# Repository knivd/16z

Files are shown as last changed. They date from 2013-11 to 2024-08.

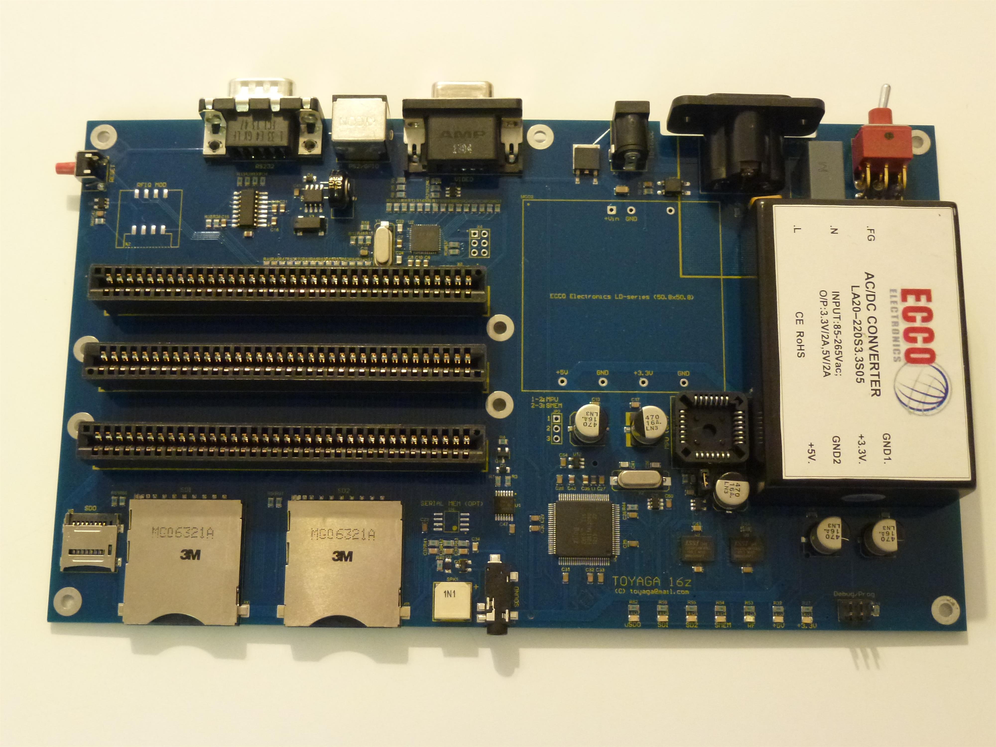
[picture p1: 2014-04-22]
graphics/P1010165.JPG

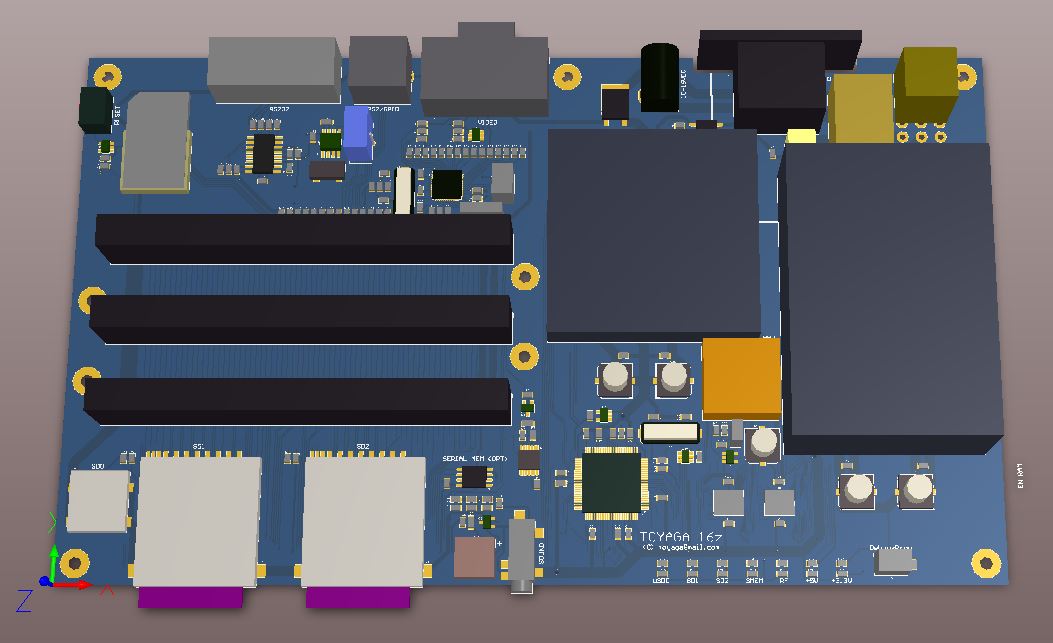
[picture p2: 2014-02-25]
graphics/3D.JPG

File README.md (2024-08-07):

16z
===

The 'Contemporary Retro' Computer

'640K ought to be enough for anyone...'

Although it is now known that Bill Gates never actually said this, whoever did was probably not far from the truth. How the resources in a system are used by the software is what really matters. Of course, this assumes a system is properly designed to utilise well-written software.

Personal computing has come a long way, but that doesn't mean the path was always ideal. There are still numerous real-life applications where an old DOS-based (or similar) machine works just as well, if not better, than the latest multicore, gigahertz beast running the most recent colourful software disaster. Along the way, computers have somehow lost their direction, and users have lost their enthusiasm and inspiration.

This project is about a computer built in the spirit of the old ways, taking inspiration from where things went wrong and attempting to rectify it by creating a retro-style computer with modern 21st-century components. Large memory and maximum speed are not the aims, nor are great graphics or the ability to run any 'nix OS. Instead, the focus is on being 'cute' (as much as you can apply that to a board), inspiring, open, and allowing the easy creation of user-designed add-on boards in any hobby lab.

Zilog's Z16F is a true gem among today's processors, dominated by Intel, ARM, and MIPS. Although it operates at a frequency considered very low by modern standards, it is amazing due to its very clean and well-thought-out internal architecture. It is also one of the very few Von-Neumann architecture CISC processors available on the market now, making it highly suitable for early introduction into microprocessor systems design and programming. Its parameters and structure revive that long-forgotten urge to create—a processor in the real style of the 'golden age' of personal computing.

The ultimate aim: to be simple and accessible to literally everyone and to demonstrate that a good, usable computer does not need 'giga'-parameters. It is all a matter of properly written software.

Possible applications: accounting, early programming education, data terminals, retro-style gaming, hobby design, and programming.

And most importantly, to bring some entertainment while working on it...

Check out the project's Wiki pages for more detailed information.

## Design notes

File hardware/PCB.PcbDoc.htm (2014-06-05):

Reporting Options

# File in Previous Format

Date | : | 5/06/2014
Time | : | 10:54:14 AM
Filename | : | D:\Work\16z\hardware\PCB.PcbDoc

Version | Warning
Release 14 | CAUTION - The Differential Pairs Routing rule added support for control of the width. Be aware that Width rules pertaining to differential pairs need to be manually moved to the Differential Pairs Routing rule.

This file was generated by an earlier version of the software

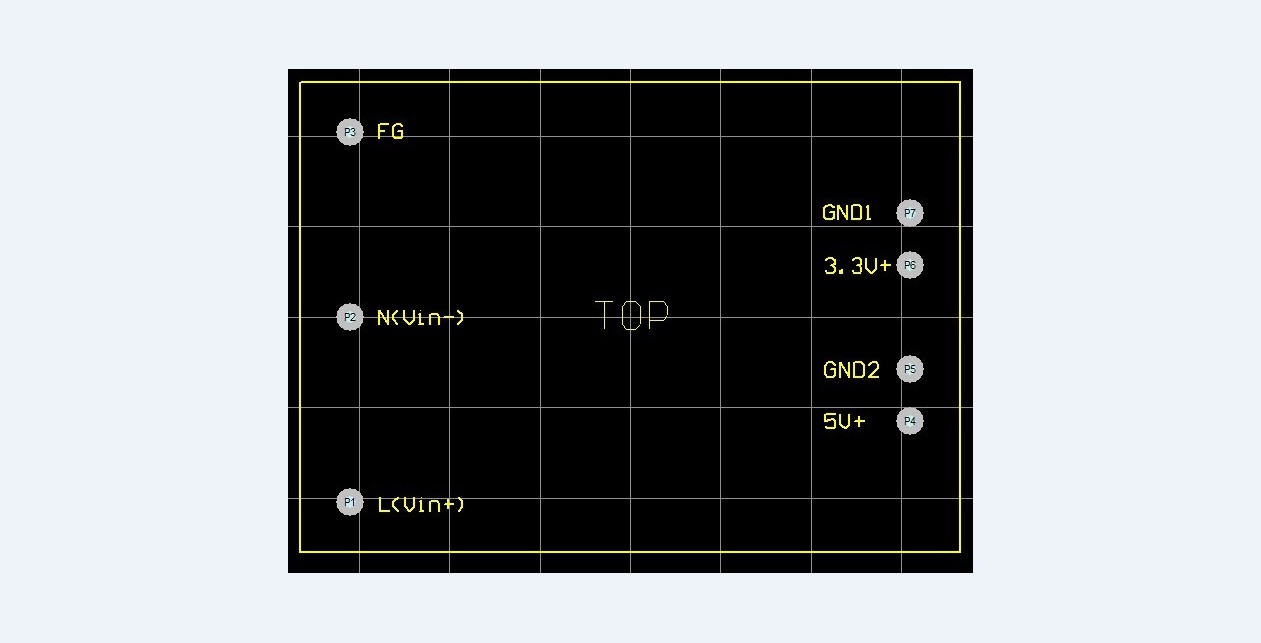
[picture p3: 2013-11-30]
docs/LA20-220S3.3S05.jpg

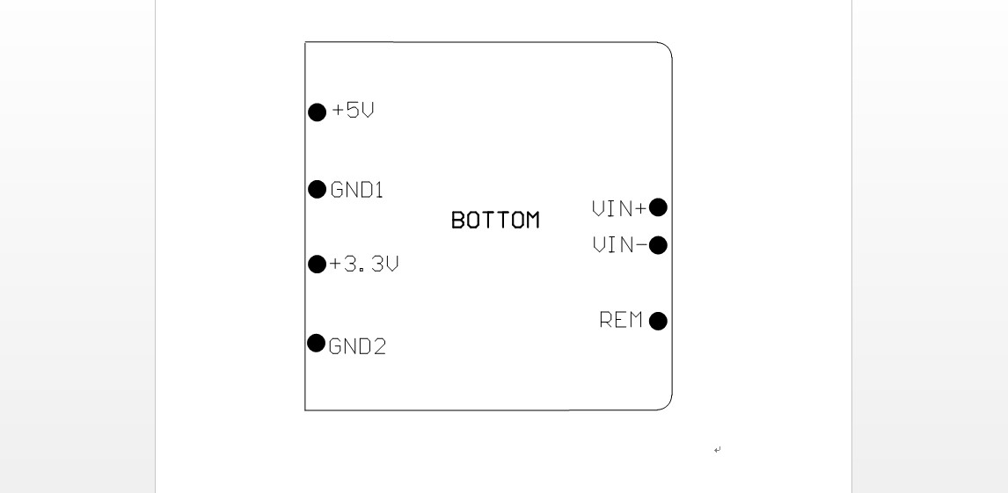
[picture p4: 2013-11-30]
docs/LD20-12S05S3.3.jpg

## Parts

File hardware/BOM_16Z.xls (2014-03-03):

Comment | Pattern | Quantity | Vendor 1 | Order Code 1 | Vendor 2 | Order Code 2 | Components | Description
LA25-220S3.3S05 | ECCO AC-DC (70x48) | 1 | ECCO | LA25-220S3.3S05 | ECCO | LA25-220S3.3S05 | MOD1 | Miniature AC/DC module
LD25-12S05S3.3 | ECCO DC-DC (50.8x50.8) | 1 | ECCO | LD25-12S05S3.3 | ECCO | LD25-12S05S3.3 | MOD2 | Miniature DC/DC module
KON-SIM-01 | KON-SIM-01 | 1 | IQRF | KON-SIM-01 | IQRF | KON-SIM-01 | X2 | SIM/microSIM 6-pin connector
470u/16V | 8.5 x 8.5 | 5 | Mouser | 661-EMZJ160A471MHA0G | Digikey | PCE3892CT-ND | C1, C9, C12, C18, C51 | Polar capacitor
1u/50V | _1206 | 1 | Mouser | 77-VJ1206V105MXATBC | Digikey | 1276-1068-1-ND | C14 | Capacitor
R46KI3330 | X2_15MM | 1 | Mouser | 80-R46KI333050N1M | Digikey | 399-6809-ND | C2 | Capacitor
27p | _0805 | 2 | Mouser | 77-VJ0805A270GXXPBC | Digikey | 1276-1285-1-ND | C22, C24 | Capacitor
100n | _0805 | 26 | Mouser | 77-VJ0805Y104MXXAC | Digikey | 1276-1003-1-ND | C3, C8, C11, C13, C17, C23, C25, C26, C27, C28, C29, C30, C31, C32, C33, C42, C43, C44, C45, C46, C47, C49, C50, C52, C53, C54 | Capacitor
470n | _0805 | 1 | Mouser | 77-VJ0805Y474JXJTBC | Digikey | 1276-1039-1-ND | C34 | Capacitor
18p | _0805 | 2 | Mouser | 77-VJ0805A180GXACBC | Digikey | 1276-1107-1-ND | C36, C41 | Capacitor
4n7 | _0805 | 4 | Mouser | 77-VJ0805Y472KXAMC | Digikey | 1276-1155-1-ND | C4, C37, C38, C39 | Capacitor
10u | _0805 | 1 | Mouser | 810-C2012X5R1A106K-3 | Digikey | 1276-1096-1-ND | C40 | Capacitor
EECS0HD334V | D10.5 x L5.5 | 1 | Mouser | 667-EEC-S0HD334V | Digikey | P11065-ND | C48 | Polar capacitor
4u7 | _0805 | 3 | Mouser | 77-VJ0805V475ZXQTBC | Digikey | 1276-1065-1-ND | C5, C6, C10 | Capacitor
1u | _0805 | 7 | Mouser | 77-VJ0805V105ZXJCBC | Digikey | 1276-1029-1-ND | C7, C15, C16, C19, C20, C21, C35 | Capacitor
BAT54WS | SOD-323 (MicroMELF) | 2 | Mouser | 78-BAT54WS-E3-08 | Digikey | BAT54WS-TPCT-ND | D1, D3 | Schottky diode
BAS21VD | SOT23-6 | 1 | Mouser | 771-BAS21VD135 | Digikey | 568-5819-1-ND | D2 | Diode (triple)
RB751V40T1G | SOD-323 (MicroMELF) | 1 | Mouser | 863-RB751V40T1G | Digikey | 568-8119-1-ND | D4 | Schottky diode
TRF600-150-2 | Fuse 5.1mm pitch | 1 | Mouser | 650-TRF600-150-2 | Digikey | TRF600-150-ND | F1 | Resettable fuse
MD-60SM | MD-60SM | 1 | Mouser | 806-KMDLX-6S-AS | Digikey | P-2260-ND | J1 | 6-pin mini-DIN connector (female) PS/2
TE1734530 | DB15F R/A VGA | 1 | Mouser | 571-1-1734530-1 | Digikey | A35116-ND | J2 | DB15 (3 rows) connector R/A
DB9-M | DB9M R/A | 1 | Mouser | 649-ID09P33E4GX00LF | Digikey | S9575-ND | J3 | DB9 connector
STX-3500-5N | STX-3500 | 1 | Mouser | 806-STX-3500-5NTR | Digikey | SC1489-1-ND | J4 | Phono Jack (stereo)
SIL2-M | 2011-2X02S | 1 | Mouser | 649-68000-202HLF | Digikey | 952-1770-ND | JP1 | Single row, 2-way connector/jumper
SIL3-M | 2011-2X03S | 1 | Mouser | 649-68000-203HLF | Digikey | 952-1777-ND | JP2 | Single row, 3-way connector/jumper
FR120R | _0805 | 1 | Mouser | 623-2508056007Z0 | Digikey | MH2029-600YCT-ND | L1 | Inductor
0805GRN | _0805+ | 2 | Mouser | 720-LGR971-KN-1 | Digikey | 475-1410-1-ND | LED1, LED2 | Light Emitting Diode
0805BLU | _0805+ | 1 | Mouser | 859-LTST-C171TBKT | Digikey | 732-4982-1-ND | LED3 | Light Emitting Diode
0805YLW | _0805+ | 3 | Mouser | 720-LYR976-PS-36 | Digikey | 475-2560-1-ND | LED4, LED5, LED6 | Light Emitting Diode
0805RED | _0805+ | 1 | Mouser | 720-LSR976-NR-1 | Digikey | 475-1278-1-ND | LED7 | Light Emitting Diode
MMUN2233 | SOT23-3 | 2 | Mouser | 863-MMUN2233LT1G | Digikey | MMUN2233LT1GOSCT-ND | Q1, Q3 | NPN biased bipolar transistor
DMP4015SK3 | TO252-3N | 1 | Mouser | 621-DMP4015SK3-13 | Digikey | DMP4015SK3-13DICT-ND | Q2 | P-channel FET transistor
470k | _0805 | 2 | Mouser | 660-RK73H2ATTD4703F | Digikey | P470KCCT-ND | R1 | Resistor
470R | _0805 | 3 | Mouser | 660-RK73H2ATTD4700F | Digikey | P470CCT-ND | R11, R19, R31 | Resistor
100k | _0805 | 10 | Mouser | 660-RK73H2ATTD1003F | Digikey | P100KCCT-ND | R2, R4, R35, R36, R49, R56, R57, R60, R61, R71 | Resistor
75R | _0805 | 3 | Mouser | 660-RK73H2ATTD75R0F | Digikey | P75.0CCT-ND | R21, R22, R23 | Resistor
510R | _0805 | 6 | Mouser | 660-RK73H2ATTD5100F | Digikey | P510CCT-ND | R27, R53, R54, R55, R59, R62 | Resistor
330R | _0805 | 4 | Mouser | 660-RK73H2ATTDD3300F | Digikey | P330CCT-ND | R28, R30, R33, R34 | Resistor
10k | _0805 | 20 | Mouser | 660-RK73H2ATTD1002F | Digikey | P10.0KCCT-ND | R3, R12, R15, R39, R45, R46, R47, R48, R50, R51, R52, R58, R63, R64, R65, R66, R67, R68, R69, R70 | Resistor
820R | _0805 | 1 | Mouser | 660-RK73H2ATTDD8200F | Digikey | P820CCT-ND | R32 | Resistor
33R | _0805 | 1 | Mouser | 660-RK73H2ATTD33R0F | Digikey | P33.0CCT-ND | R40 | Resistor
20R | _0805 | 1 | Mouser | 660-RK73H2ATTD20R0F | Digikey | P20.0CCT-ND | R44 | Resistor
15k | _0805 | 3 | Mouser | 660-RK73H2ATTD1502F | Digikey | P15.0KCCT-ND | R5, R13, R20 | Resistor
8k2 | _0805 | 3 | Mouser | 660-RK73H2ATTD8201F | Digikey | P8.20KCCT-ND | R6, R14, R24 | Resistor
1k | _0805 | 9 | Mouser | 660-RK73H2ATTD1001F | Digikey | P1.00KCCT-ND | R7, R10, R18, R29, R37, R38, R41, R42, R43 | Resistor
3k9 | _0805 | 3 | Mouser | 660-RK73H2ATTD3901F | Digikey | P3.90KCCT-ND | R8, R16, R25 | Resistor
2k | _0805 | 3 | Mouser | 660-RK73H2ATTD2001F | Digikey | P2.00KCCT-ND | R9, R17, R26 | Resistor
SDR08540M3 | SDR08540M3-01 | 1 | Mouser | 810-SDR08540M3-01 | Digikey | 445-4832-1-ND | SPK1 | Speaker/Buzzer
E201MD1ABE | E201MD1ABE | 1 | Mouser | 611-E201-001 | Digikey | CKN1521-ND | SW1 | Switch
SKHHLSA010 | SKHH-HORIZONTAL | 1 | Mouser | 688-SKHHLS | Digikey | EG1840-ND | SW2 | Switch, Momentary, Normal Open
SN74LVC00APW | TSOP65P640-14N | 1 | Mouser | 595-SN74LVC00APWR | Digikey | 296-1216-1-ND | U1 | Quad NAND
SN74AUP1G57DBV | SOT23-6 | 1 | Mouser | 595-SN74AUP1G57DBVR | Digikey | 296-19082-1-ND | U10 | Programmable logic element
SN74LVC1G126DBV | SOT23-5 | 1 | Mouser | 595-74LVC1G126DBVRG4 | Digikey | 296-11605-1-ND | U11 | Buffer gate with non-invertinng Enable input
SN74AHC1G08DBV | SOT23-5 | 1 | Mouser | 595-SN74AHC1G08DBVR | Digikey | 296-1091-1-ND | U12 | 2-INPUT AND GATE
FT800Q | QFN50P700X700-48W2N | 1 | Mouser | 895-FT800Q-R | Digikey | 768-1185-1-ND | U2 | Embedded Video Engine
MAX3232D | SOIC16 | 1 | Mouser | 595-MAX3232ECDR | Digikey | 296-13094-1-ND | U3 | Dual EIA-232 drivers
Z16F2811AL20EG | LQFP100 | 1 | Mouser | 692-Z16F2811AL20SG | Digikey | 269-4533-ND | U5 | 16-bit microcontroller/microprocessor
MCP1319MT-29LE/OT | SOT23-5 | 1 | Mouser | 579-MCP1319MT29LE/OT | Digikey | MCP1319MT-29LE/OTCT-ND | U6 | Voltage Supervisor
IS66WVE4M16BLL | BGA75P6X8-48 | 2 | Mouser | 870-66WVE4M16BLL70BL | Digikey | Not available | U7, U8 | 4M x 16 high speed asynchronous pseudostatic RAM
ISL12024IBZ | SOIC8 | 1 | Mouser | 968-ISL12024IBZ-T | Digikey | ISL12024IBZ-TCT-ND | U9 | Real-Time Clock/Calendar with Embedded Unique ID
LTV354T | SO4 | 1 | Mouser | 859-LTV-354T | Digikey | 160-1333-1-ND | UC1 | Optocoupler AC
771W-AX2/01 | 771W-AX2/01 | 1 | Mouser | 562-771W-AX2/01 | Digikey | Q310-ND | X1 | Single row, 3-way connector
SD-RSMT | SD-RSMT | 2 | Mouser | 517-SD-RSMT-2-MQ | Digikey | 3M5646CT-ND | X10, X11 | SD card connector
47219-2001 | MOLEX_47219-2001 | 1 | Mouser | 538-47219-2001 | Digikey | WM6698CT-ND | X12 | microSD card connector
8428-11B1-RK-TP | PLCC28-T/H socket | 1 | Mouser | 517-8428-11B1-RK-TP | Digikey | 3M2811B1-ND | X13 | PLCC28 T/H socket
PJ-002A | KLD-0202 | 1 | Mouser | 163-7620E-E | Digikey | CP-002A-ND | X3 | Power Jack 2.1mm or 2.5mm
745-072-520-206 | 745-072-520-206 | 3 | Mouser | 587-745-072-520-206 | Digikey | A31721-ND | X5, X6, X7 | Dual row, 72-way connector
DIL6-M | 2011-2X03S | 1 | Mouser | 649-68602-406HLF | Digikey | 952-1779-ND | X9 | Dual row, 6-way connector
ABLS-12.000MHZ | HC49/SMT | 1 | Mouser | 815-ABLS-12-B2 | Digikey | 535-9067-1-ND | Y1 | Crystal Resonator
ABLS-18.432MHZ-B2-T | HC49/SMT | 1 | Mouser | 815-ABLS-18.432-B2 | Digikey | 535-9072-1-ND | Y2 | Crystal Resonator
CM200C-32.768KDZF-UT | Crystal 79X37 (4) | 1 | Mouser | 695-CM200C-327KF-U | Digikey | 300-8740-1-ND | Y3 | Crystal Resonator
DNF | SOIC127P760-8N | 1 |  |  |  |  | U4 | Standard 8-pin SPI memory
DNF | 2011-2X03S | 1 |  |  |  |  | X4 | Dual row, 6-way connector
DNF | 2011-1X04S | 1 |  |  |  |  | X8 | Single row, 4-way connector

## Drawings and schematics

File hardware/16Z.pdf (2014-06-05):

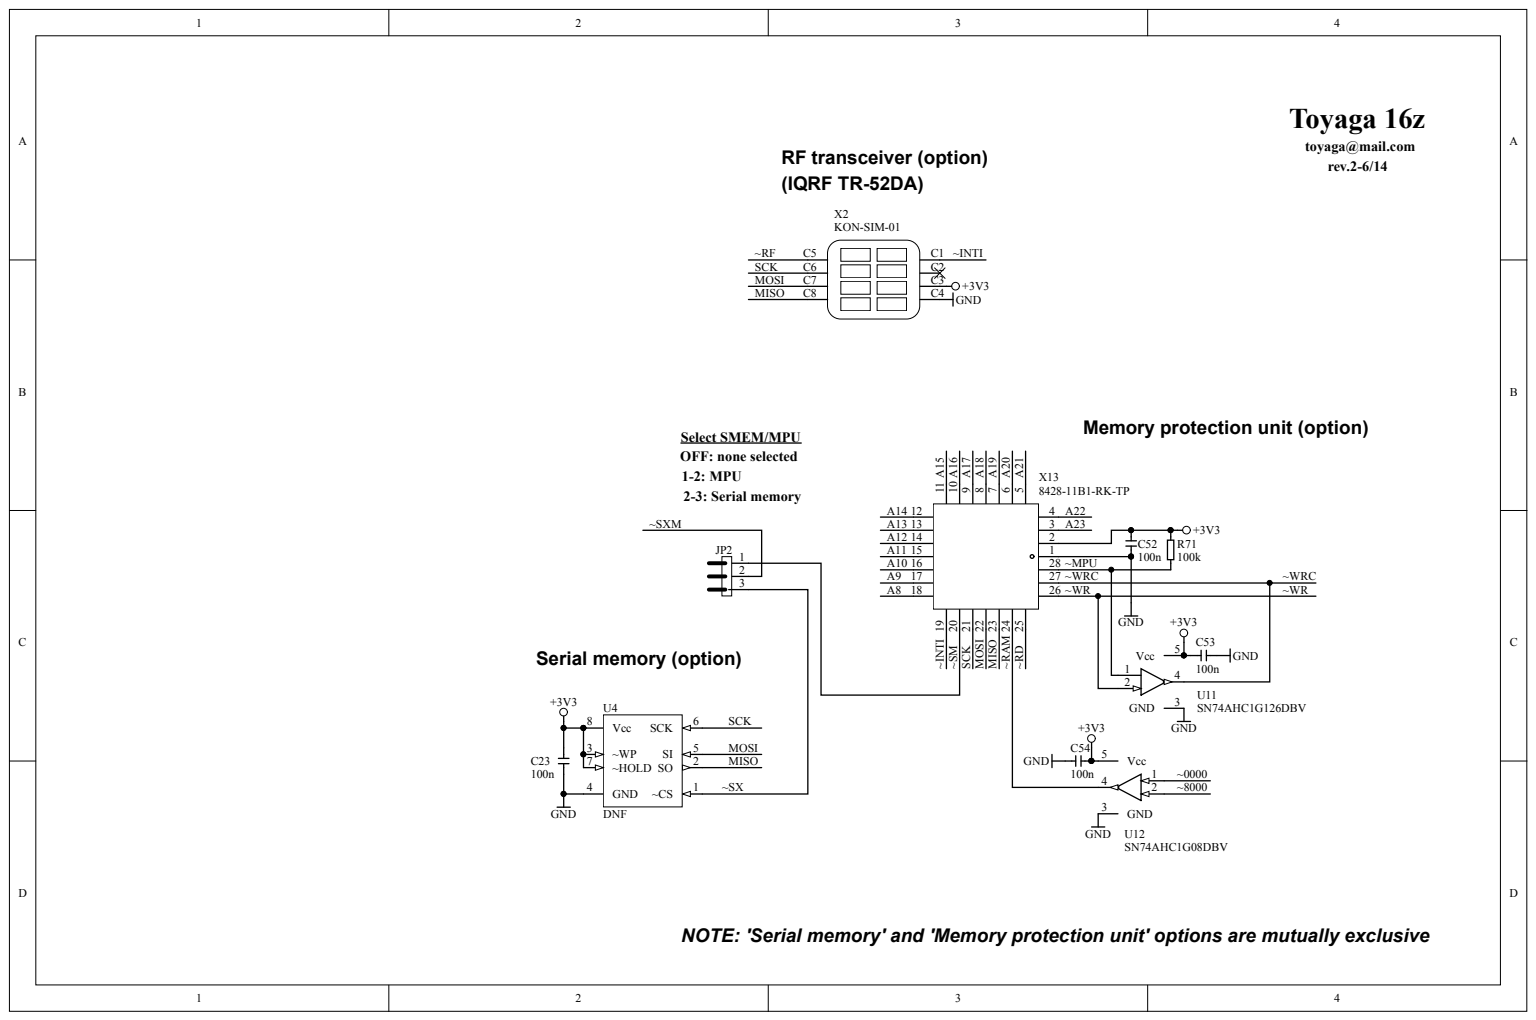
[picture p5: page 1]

Memory protection unit (option)

SCK

~HOLD 7 | | MISO

GND 4 | | ~SX

NOTE: 'Serial memory' and 'Memory protection unit' options are mutually exclusive

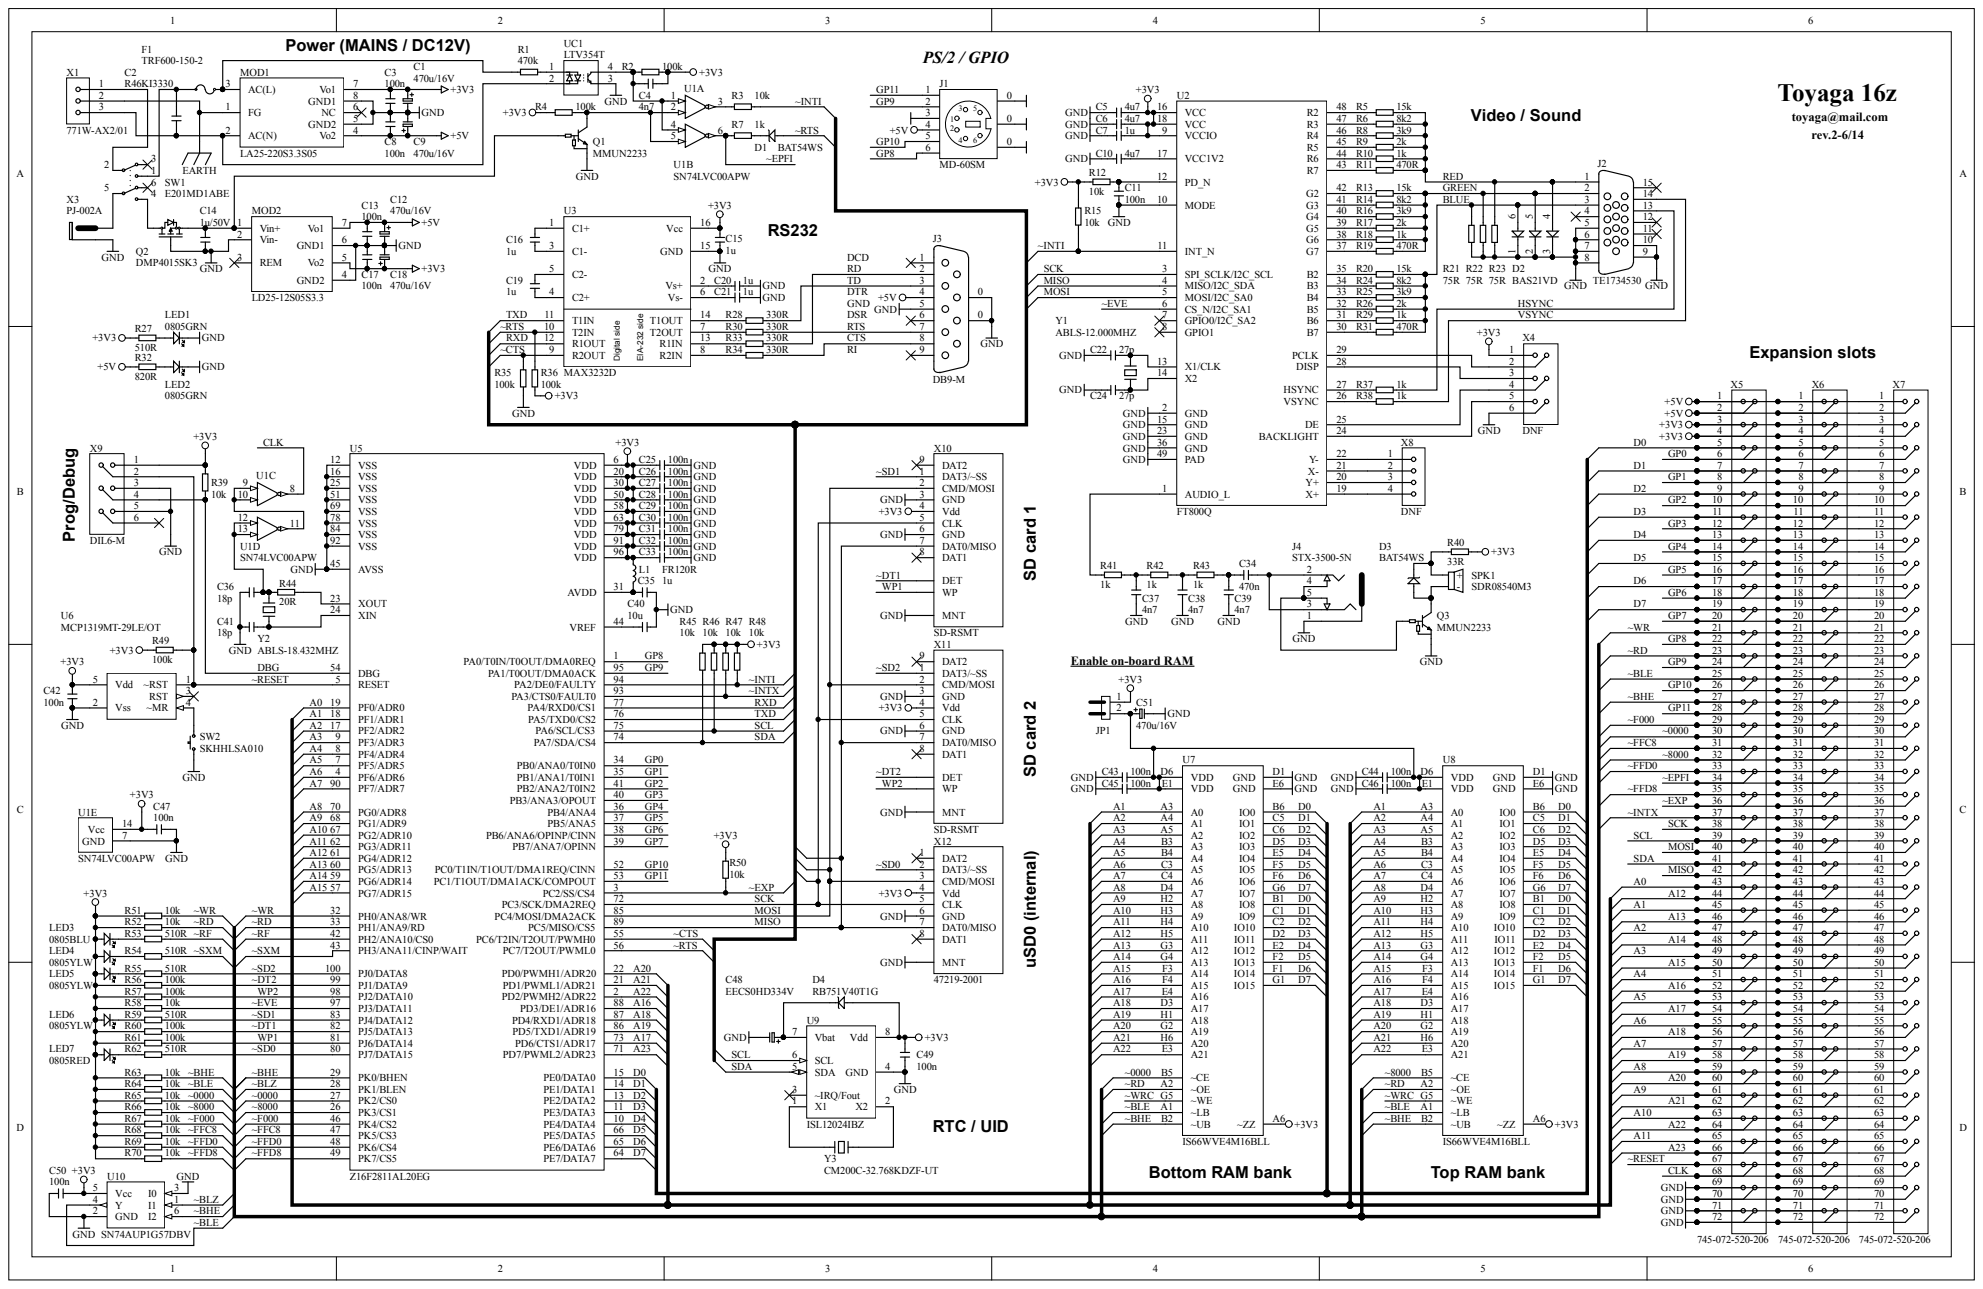
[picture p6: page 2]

6 R4 7 R4 8 k 1 0 k 1 0 k +3V3 | X1 0 | 2 3 | 2 | GND

uSD0 (internal) SD card 1 SD card 2

SDA SCL RXD TXD

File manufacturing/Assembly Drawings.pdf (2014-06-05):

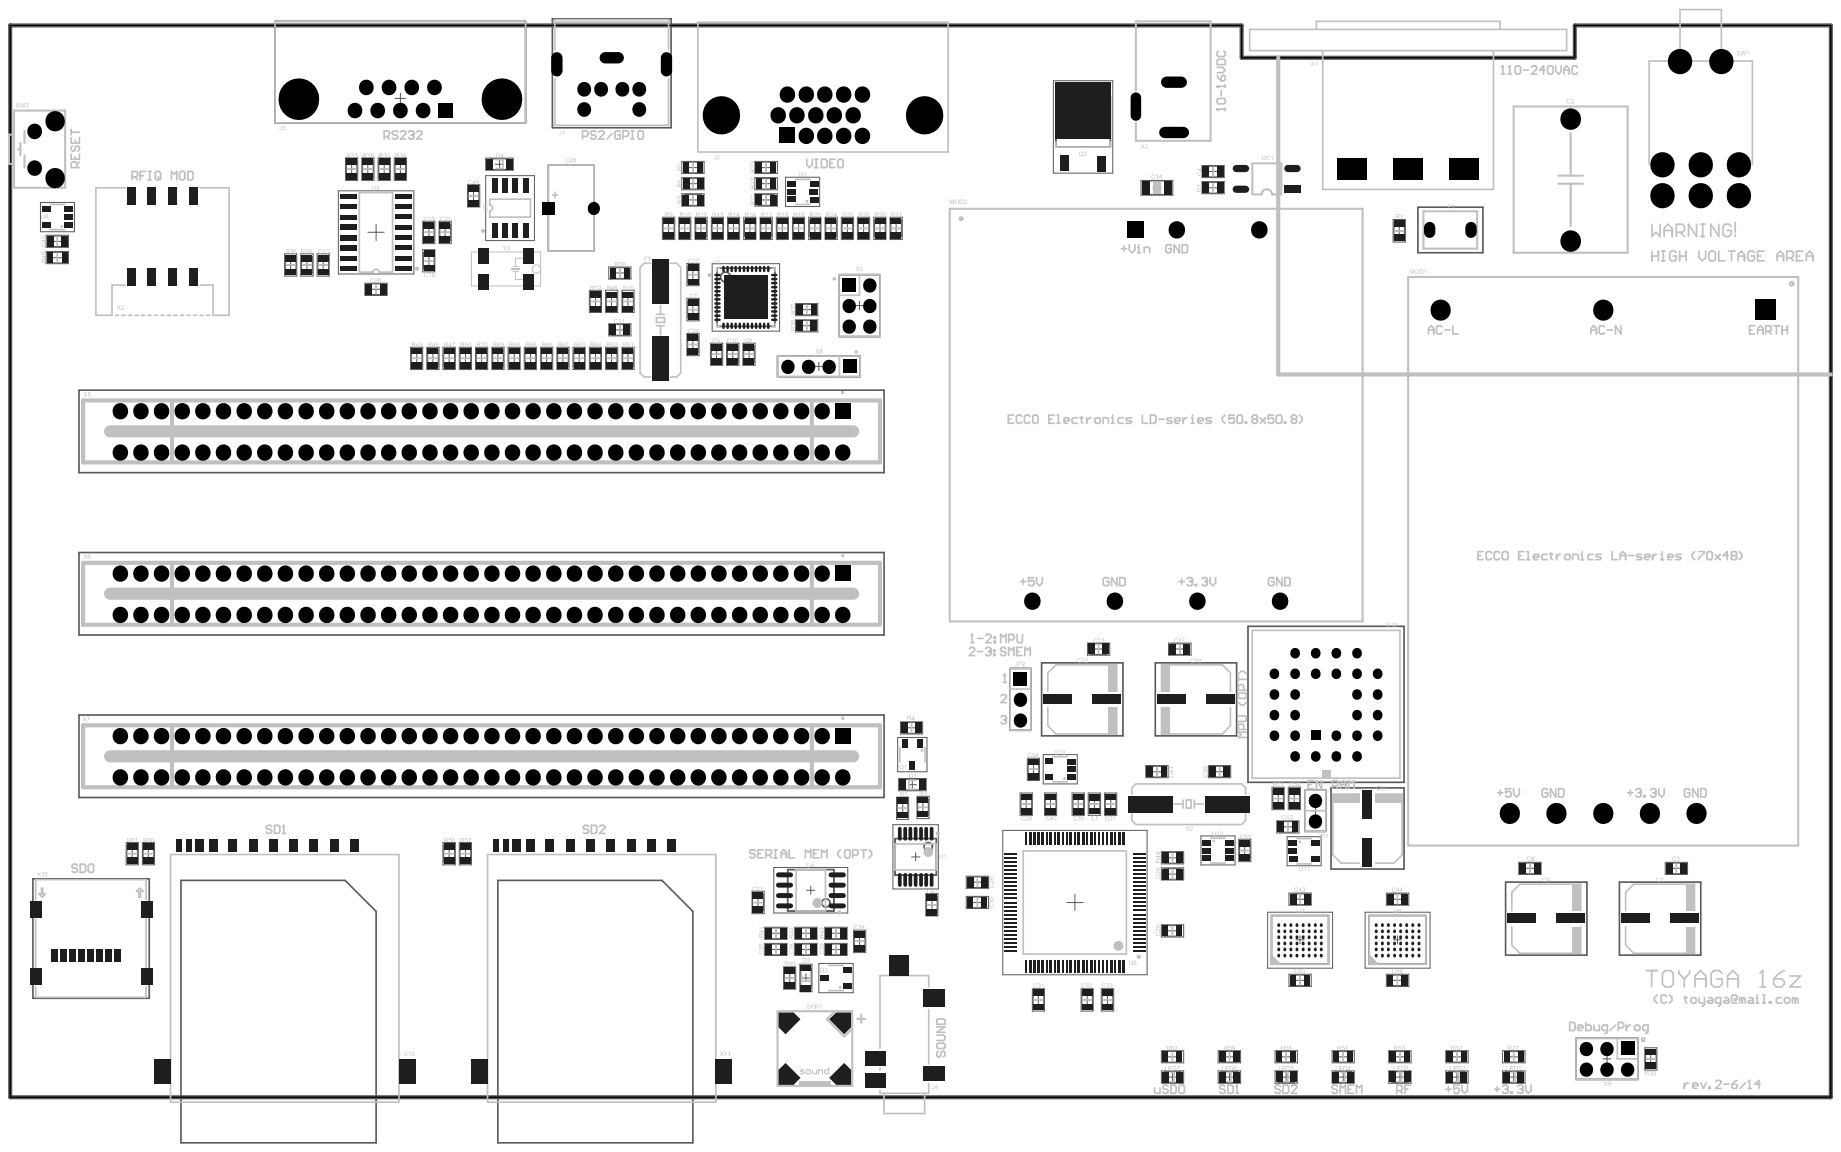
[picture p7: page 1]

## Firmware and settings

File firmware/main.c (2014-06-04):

#include <zneo.h>
#include <stdio.h>
#include "main.h"
#include "uart0.h"
#include "memory.h"
#include "spi.h"

FLASH_OPTION3=0x7f;

unsigned char sys_flags=0;	// system flags (see SYS_FLG_xxx constants)


void main(void) {

	WDTH=0x55; WDTH=0xaa; WDTHL=10000;	// initialise the watchdog reload register for 1s interval

	OSCDIV=0x00;	// no divider for the oscillator
    OSCCTL=0xe7; OSCCTL=0x18;	// unlock the oscillator control
    OSCCTL=0xf8;	// enable the external crystal oscillator and prepare the watchdog for later use
    asm("LD R0,#500000");   // a small delay for crystal oscillator stabilisation
    asm("label1: NOP");
    asm("DJNZ R0,label1");
	OSCCTL=0xe7; OSCCTL=0x18;	// unlock the oscillator control
    OSCCTL|=0x01;	// select the external crystal oscillator

	PADD=0xff; PBDD=0xff; PCDD=0x7b; PDDD=0xff; PEDD=0xff; PFDD=0xff; PGDD=0xff; PHDD=0xf3; PJDD=0x66; PKDD=0xff;	// set port directions
	PAHDE=0xff; PBHDE=0xff; PCHDE=0xff; PDHDE=0xff; PEHDE=0xff; PFHDE=0xff; PGHDE=0xff; PHHDE=0xff; PJHDE=0xff; PKHDE=0xff; // enable high current drive for all ports
	PAAFL=0xf0; PCAFL=0x38; PDAFH=0xff; PFAFL=0xff; PGAFL=0xff; PHAFH=0x03; PKAFL=0xfd;	// set port functions
	PCOUT=0xff; PHOUT=0xff; PJOUT=0xff;	// default high state for some ports
	
	// these will be set by the linker anyway
	EXTCS0=0x9001; EXTCS1=0x9001; EXTCS2=0x9011; EXTCS3=0x9015; EXTCS4=0x9015; EXTCS5=0x9015;
	EXTCT=0x40; 	// enable and configure the external interface
    
    // ==================== no C variables before this point since the external bus won't be configured yet ============================


	uart0_init(57600);	// initialise UART with default parameters (57600,8N1)

	memory_build_map();	// initialise and test the available memory and build memory map


	// ### for testing only - to be removed
	printf("\rTesting RAM ");
	{	
		unsigned long step=0x10000;
		unsigned long a, z=0;		
		for(a=0; a<0xf00000; a+=step) {
			z+=memory_test(a,step);
			printf("\r%d bytes free ",z);
		}
	}
	printf("\r\nDone.\r\n\n");





	EI();	// enable interrupts	
	while(1) {

		


    
    }
}

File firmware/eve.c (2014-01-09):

#include <zneo.h>
#include "eve.h"
#include "spi.h"	// EVE is controlled via SPI
#include "main.h"	// SPI device select signals in 16z are defined here


void eve_wr8(unsigned long addr, unsigned char d) {
	spi_select(EVE);
	addr&=0x3fffff;
	addr|=0x800000;	// write commands have '10' in bits [23,22]
	spi_rw((unsigned char)(addr>>16));
	spi_rw((unsigned char)(addr>>8));
	spi_rw((unsigned char)addr);
	spi_rw(d);
	spi_unselect();
}


void eve_wr16(unsigned long addr, unsigned short d) {
	spi_select(EVE);
	addr&=0x3fffff;
	addr|=0x800000;	// write commands have '10' in bits [23,22]
	spi_rw((unsigned char)(addr>>16));
	spi_rw((unsigned char)(addr>>8));
	spi_rw((unsigned char)addr);
	spi_rw((unsigned char)d);
	spi_rw((unsigned char)(d>>8));
	spi_unselect();
}


void eve_wr32(unsigned long addr, unsigned long d) {
	spi_select(EVE);
	addr&=0x3fffff;
	addr|=0x800000;	// write commands have '10' in bits [23,22]
	spi_rw((unsigned char)(addr>>16));
	spi_rw((unsigned char)(addr>>8));
	spi_rw((unsigned char)addr);
	spi_rw((unsigned char)d); 
	spi_rw((unsigned char)(d>>8)); 
	spi_rw((unsigned char)(d>>16)); 
	spi_rw((unsigned char)(d>>24));
	spi_unselect();
}


unsigned char eve_rd8(unsigned long addr) {
	unsigned char d;
	spi_select(EVE);
	addr&=0x3fffff;	// read commands have '00' in bits [23,22]
	spi_rw((unsigned char)(addr>>16));
	spi_rw((unsigned char)(addr>>8));
	spi_rw((unsigned char)addr);
	spi_rw(0);	// dummy byte
	d=spi_rw(0);
	spi_unselect();
	return d;
}


unsigned short eve_rd16(unsigned long addr) {
	unsigned short d;
	spi_select(EVE);
	addr&=0x3fffff;	// read commands have '00' in bits [23,22]
	spi_rw((unsigned char)(addr>>16));
	spi_rw((unsigned char)(addr>>8));
	spi_rw((unsigned char)addr);
	spi_rw(0);	// dummy byte
	d=((unsigned short)spi_rw(0)+((unsigned short)spi_rw(0)<<8));
	spi_unselect();
	return d;
}


unsigned long eve_rd32(unsigned long addr) {
	unsigned long d;
	spi_select(EVE);
	addr&=0x3fffff;	// read commands have '00' in bits [23,22]
	spi_rw((unsigned char)(addr>>16));
	spi_rw((unsigned char)(addr>>8));
	spi_rw((unsigned char)addr);
	spi_rw(0);	// dummy byte
	d=((unsigned long)spi_rw(0)+((unsigned long)spi_rw(0)<<8)+((unsigned long)spi_rw(0)<<16)+((unsigned long)spi_rw(0)<<24));
	spi_unselect();
	return d;
}


void eve_cmd(unsigned char cmd) {
	spi_select(EVE);
	cmd&=0x3f;
	cmd|=0x40;	// commands have '01' in bits [7,6]
	spi_rw(cmd);
	spi_rw(0);
	spi_rw(0);
	spi_unselect();
}


void eve_init(unsigned short xres, unsigned short yres) {





	
	eve_cmd(EVE_CMD_ACTIVE);
	eve_cmd(EVE_CMD_CLKEXT);
	eve_wr8(EVE_REG_GPIO,0x10);
	eve_wr8(EVE_REG_PCLK,2);

}

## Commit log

2013-11-23 Initial upload
    All datasheets and other information about the parts used in the
    hardware.
    The Altium project as of today.
    [16Z.PrjPcb, 16Z.SCHLIB, Schematic.SchDoc]
2013-11-23 Corrections to schematic and footprints
    The schematic has been corrected according to ECCO's offer for AC/DC and
    DC/DC modules and all component footprints have been added and made into
    libraries
    [16Z.PcbLib, 16Z.PrjPcb, 16Z.SCHLIB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]
2013-11-24 Updated schematic and begin of PCB routing
    The schematic now uses an IEC input connector for the AC power.
    LD20 DC/DC module is changed to LD25 (50.8x50.8 footprint).
    Proposed PCB size 264x132mm with 20mm between the slots.
    [16Z.PcbLib, 16Z.SCHLIB, PCB.PcbDoc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]
2013-11-24 No DBG on the slot
    The DBG signal is not needed on the expansion slots. Instead the CLK
    signal which carries the system clock of 19.6608MHz has been introduced
    on pin 68 of the expansion slots.
    [PCB.PcbDoc, Schematic.SchDoc]
2013-11-24 Optimisations
    Consolidated the NOR gates into a single IC.
    A better PCB layout allows reducing the board size to 224x132mm with
    more room for add-on boards.
    [16Z.PcbLib, 16Z.SCHLIB, PCB.PcbDoc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]
2013-11-25 PCB work
    [16Z.PcbLib, PCB.PcbDoc, Schematic.SchDoc]
2013-11-28 Initial release of the hardware
    Should be ready for manufacturing now.
    The BOM contains most of the parts with sourcing references (except for
    the very generic ones).
    PCB factories need the files from the "manufacturing" folder (only).
    [16Z.PcbLib, 16Z.PrjPcb, BOM_16Z.xls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]
2013-11-28 Increased clearance for the large bottom polygons
    [16Z.PrjPcb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]
2013-11-28 Updated BOM with references for all parts
    [BOM_16Z.xls]
2013-11-29 Changed DC module footprint
    ECCO provided a different footprint for their DC module, which prompted
    a little change in the PCB. Now the two footprints have been verified by
    the manufacturer.
    [16Z.PcbLib, 16Z.PrjPcb, 16Z.SCHLIB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]
2013-11-29 Final cosmetic touches in the BOM
    [BOM_16Z.xls, PCB.PcbDoc, Schematic.SchDoc]
2013-11-30 Add-on PCB templates
    Three 'standard' sizes for add-on boards for 16z.
    Altium Designer library
    [16z_addons.PcbLib, 16z_addons.SchLib]
2013-12-04 Updated capacitor values in accordance with the BOM
    [PCB.PcbDoc, Schematic.SchDoc]
2013-12-19 Improvements
    Improved add-on libraries
    Added PCB prototype add-on boards
    [16z_addons.SchLib, TypeA_proto.PcbDoc, TypeB_proto.PcbDoc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]
2013-12-19 Corrected wrong sourcing reference for UC1 Added manufacturing files for all three sizes of proto boards
    [BOM_16Z.xls, PCB.PcbDoc, Schematic.SchDoc]
2013-12-24 PCB corrections after the first prototype board
    Corrected hole size on the expansion slots (corrected in the library as
    well)
    Corrected positions of the AC inlet and the power switch
    [16Z.PcbLib, 16Z.PrjPcb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]
2013-12-24 PCB corrections after the first prototype board
    Corrected supercap hole size
    [16Z.PcbLib, 16Z.PrjPcb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]
2013-12-24 Small PCB corrections
    PCB corrections based on the first prototype board to adjust the AC
    inlet position
    [16Z.PrjPcb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]
2013-12-26 Added GP8 and GP9 to the PS/2 connector
    [16Z.PrjPcb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]
2013-12-27 Corrected inverted footprint for the DC converter
    [16Z.PcbLib, 16Z.PrjPcb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]
2013-12-30 Small document adjustments
    [BOM_16Z.xls]
2013-12-31 Small cosmetic change on the board
    Moved the four filtering capacitors by a small distance further away
    from the converters
    [16Z.PrjPcb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]
2014-01-02 Improved proto boards
    [BOM_16Z.xls, TypeA_proto.PcbDoc, TypeB_proto.PcbDoc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]
2014-01-02 Fixed component and PCB libraries
    [16Z.PcbLib, 16Z.PrjPcb, 16Z.SCHLIB]
2014-01-04 reordered LED colours
    [BOM_16Z.xls, PCB.PcbDoc, Schematic.SchDoc]
2014-01-05 Replaced the CPU crystal with 18.432MHz one
    This change provides much better options for correct serial port
    baudrates on the expense of slightly underclocking the system
    [16Z.PrjPcb, 16Z.SCHLIB, BOM_16Z.xls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]
2014-01-06 The beginning of the firmware for 16z
    Early hardware initialisation
    Routine functions for memory test and mapping
    Basic UART functions
2014-01-09 Initial work on several software support functions
    Memory, UART0, SPI and the EVE controller. Very patchy and nothing
    really usable yet...
2014-01-11 Cosmetic: Swapped positions of SD1 and SD2
    SD1 and SD2 card connectors were mistakenly placed in an opposite order:
    SD2 SD1. This patch fixes the situation putting SD1 on the left side and
    SD2 on the right side
    [16Z.PrjPcb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]
2014-01-24 Corrected EPFI logic function
    The ~EPFI (Early Power Failure Indication) signal in the first prototype
    board did not work due to wrongly selected logic function NOR instead of
    NAND
    [16Z.PrjPcb, 16Z.SCHLIB, BOM_16Z.xls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]
2014-01-28 Added bus logic U10
    Solves the ZNEO problem when BHEN=BLEN=0 for 16-bit data on 8-bit bus
    [16Z.PrjPcb, 16Z.SCHLIB, BOM_16Z.xls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]
2014-02-05 corrected ground polygon shape
    [PCB.GBL, PCB.GBO, PCB.GBP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]
2014-02-09 Cosmetic correction in the 16z schematic PDF
    [Schematic.SchDoc]
2014-02-21 Added a jumper to enable/disable the on-board RAM
    This jumper will allow the installation of memory cards with MMU or
    banked memory on boards with pre-loaded memory chips.
    [16Z.PcbLib, 16Z.PrjPcb, 16Z.SCHLIB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]
2014-02-21 Added a jumper to enable/disable the on-board RAM
    banked memory on boards with pre-loaded memory chips
    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
    [16Z.PrjPcb, BOM_16Z.xls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]
2014-02-25 Added optional MPU
    A socket for memory protection unit (non-existent yet)
    Some other little improvements over the schematic
    [16Z.PcbLib, 16Z.PrjPcb, 16Z.SCHLIB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]
2014-02-26 Optimised BOM
    [BOM_16Z.xls]
2014-03-03 Optimised BOM with links from Mouser and Digikey
    A mistake in the name of U11 has been fixed as well
    [16Z.PrjPcb, 16Z.SCHLIB, Additions.SchDoc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]
2014-03-03 Updated BOM with available parts from Digikey
    [BOM_16Z.xls]
2014-03-27 very small correction in the PLCC28 footprint
    Pin 1 was not marked in any way in the previous version.
    Also, two redundant via have been removed
    [16Z.PcbLib, 16Z.PrjPcb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]
2014-06-04 new PCB
    Uh... nasty crosstalk issues prompted partial redesign of the PCB.
    Fingers crossed for this one...
    [16Z.PrjPcb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]
2014-06-05 Updated CAM documents
    [16Z.PrjPcb, Additions.SchDoc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]
2014-06-05 updated schematic PDF
